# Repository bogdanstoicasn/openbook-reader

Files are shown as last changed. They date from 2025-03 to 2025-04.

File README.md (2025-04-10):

# OpenBook-reader

## Overview

OpenBook is an open-source e-book reader designed to be affordable and customizable. It is built around the ESP32-C6 microcontroller and integrates an E-Ink display, a Li-Po battery, and a microSD slot for extended storage. The device targets a wide range of users, from hobbyists to developers, who want to create their own e-book reader or modify existing designs.

## Table of Contents

1. [Features](#features)

2. [Data](#data)

3. [Block Diagram](#block-diagram)

4. [Hardware Functionality](#hardware-functionality)

5. [Hardware Components & Datasheets](#hardware-components--datasheets)

6. [Implementation](#implementation)

7. [Design Decisions and Trade-offs](#design-decisions-and-trade-offs)

8. [3D Visualizations](#3d-visualizations)
   
9. [Testing and Debugging](#testing-and-debugging)

10. [Suggestions](#suggestions)

## Features

- **Microcontroller**: ESP32-C6 with Wi-Fi and Bluetooth capabilities

- **Display**: 7.5" E-Ink display with a resolution of  800x480 pixels

- **Storage**: MicroSD card slot for additional storage

- **Battery**: Rechargeable Li-Po battery with a capacity of 2500mAh

- **Connectivity**: Wi-Fi 6, Bluetooth 5.0, and USB-C for charging and data transfer

- **Sensors**: Integrated environmental sensor (BME680) for temperature, humidity, pressure, and gas measurements

- **Real-Time Clock**: DS3231 for accurate timekeeping

- **User Interface**: 3 tactile buttons for navigation and control

## Data

Dimension: 175mm x 114mm x 10mm

Weight: 250g
Supported file formats: EPUB, PDF, TXT, FB2.

Operating system: FreeRTOS

Charging: 5V/1A via USB-C

## Block Diagram

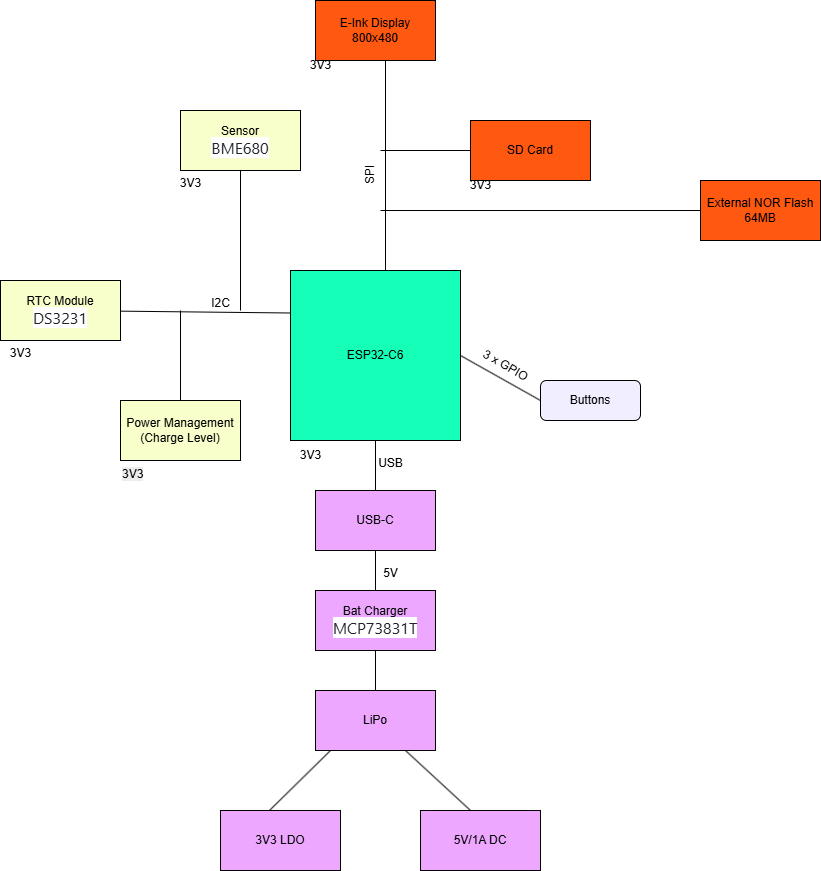
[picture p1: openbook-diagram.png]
Block Diagram


## Hardware Functionality

### Microcontroller:

The ESP32-C6 is the main processing unit, responsible for handling all system operations, including e-paper display updates, wireless communication, and power management. It features:

- RISC-V architecture 32-bit core

- 2.4 GHz Wi-Fi and Bluetooth 5.0 connectivity

-  160 MHz clock speed with 4 stage pipeline

- L1 chache 16KB

- ROM 320KB

- SRAM 512KB(HP) + 16KB (LP)

- 30 GPIO pins

Power consumption: 160uA in deep sleep mode, 10mA in active mode

### Display:

- Type: E-Ink (E-Paper) display

- Size: 7.5 inches

- Resolution:  800x480 pixels

- Communication: SPI interface

- Power consumption: ~1.2mW in active mode, ~0.1mW in standby mode

Connection to the ESP32-C6 and other modules:

> IO7 -> MOSI(14)

> IO6 -> SCK(13)

> IO10 -> EPD_CS(12)

> IO5 -> EPD_DC(11)

> IO23 -> EPD_RST(10)

> IO3 -> EPD_BUSY(9)

Connection to power:

> EPD_3V3 -> 3.3V

### MicroSD Card

- Type: MicroSD card

- Capacity: Up to 32GB (FAT32 format)

- Communication: SPI interface

- Power consumption: ~50mA during read/write operations, ~10uA in standby mode

Connection to the ESP32-C6 and other modules:

> IO7 -> MOSI(CMD)

> IO6 -> SCK(CLK)

> IO4 -> SS_SD(CD/DAT3)

> IO2 -> MISO(DAT0)

### Battery and Power Management

- Type: Li-Po battery

- Capacity: 2500mAh

- Voltage: 3.7V nominal, 4.2V max

- Voltage regulator: MCP73831T for charging and power management

- Charging: 5V/1A via USB-C

- Power consumption: ~10mA during active mode, less than 50uA in deep sleep mode

Connection to the ESP32-C6 and other modules:

> CELL -> BAT

> IO21 -> SDA(SDA)

> IO22 -> SCL(SCL)

### Environmental Sensor

- Type: BME680

- Measurement: Temperature, humidity, pressure, and gas

- Communication: I2C interface

- Power consumption: ~3.6mA during measurement, ~0.1uA in sleep mode

Connection to the ESP32-C6 and other modules:

> IO21 -> SDA(SDI)

> IO22 -> SCL(SCK)

> IO19 -> I2C_PW(VDDIO)

### Real-Time Clock

- Type: DS3231

- Function: Accurate timekeeping

- Communication: I2C interface

- Power consumption: ~1.5uA in battery backup mode, ~0.1uA in sleep mode

Connection to the ESP32-C6 and other modules:

> IO21 -> SDA(15)

> IO22 -> SCL(16)

> IO18 -> RTC_RST(RST)

> IO1 -> 32KHz(32KHz)

> IO0 -> INT_RTC(SQW/INT)

### External Nor Flash

- Type: SPI Flash

- Capacity: 64MB

- Communication: SPI interface

- Power consumption: ~10mA during read/write operations, ~0.1uA in standby mode

Connection to the ESP32-C6 and other modules:

> IO11 -> EPD_CS(CS)

> IO6 -> SCK(CLK)

> IO2 -> MISO(DO/IO1)

> IO7 -> MOSI(DI/IO0)

### USB-C Connector

- Type: USB-C connector

- Function: Charging and data transfer

- Power consumption: ~5V/1A during charging, ~0.1uA in standby mode

- Protection: PFMF varistor for ESD protection

- Diode: Schottky barrier rectifier diode for reverse polarity protection

### Buttons

- Type: Tactile push buttons

- Number: 3

- Function: User input for navigation and control

Connection to the ESP32-C6 and other modules:

> EN -> RESET

> IO9 -> IO/BOOT

> IO15 -> IO/CHANGE

### Calculations

| Component | Current Draw (mA) | Voltage (V) | Power (mW) |
|---|---|---|---|
| ESP32-C6  | 10 | 3.3 | 33 |
| E-Ink Display | 1.2 | 3.3 | 3.96 |
| MicroSD Card | 50 | 3.3 | 165 |
| BME680 | 3.6 | 3.3 | 11.88 |
| DS3231 | 0.015 | 3.3 | 0.0495 |
| MCP73831T | 10 | 3.3 | 33 |
| USB-C Connector | 5 | 5 | 25 |
| External Flash | 10 | 3.3 | 33 |

Total Power Consumption: 304.3 mW
Total Current Draw: 89.8 mA

## Hardware Components & Datasheets

| Name | Description | Num | Datasheet | Price |
|---|---|-----|---|---|
| Micro-SD | Micro-Sd | 1 | https://www.attend.com.tw/data/download/file/112A-TAAR-R03_Spec.pdf | https://www.digikey.com/en/products/detail/attend-technology/112A-TAAR-R03/17633923 |
| Inductor | 68uH | 1 | https://www.we-online.com/components/products/datasheet/784373170680.pdf | https://eu.mouser.com/ProductDetail/Wurth-Elektronik/784373170680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 |
| Led | No description | 1 | https://www.bridgelux.com/sites/default/files/resource_media/DS51_Rev%20F%20Bridgelux%20SMD%203030%20Data%20sheet.pdf | https://www.digikey.com/en/products/detail/bridgelux/BXEM-27E0000-0-000/6618599 |
| Voltage Detector | With Adjustable Delay Time | 1 | https://www.rohm.com/datasheet?p=BD5229G&dist=Digi-key&media=referral&source=digi-key.com&campaign=Digi-key | https://www.digikey.com/en/products/detail/rohm-semiconductor/BD5229G-TR/658502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 |
| Buttons | No description | 3 | https://configured-product-images.s3.amazonaws.com/Datasheets/TL3315.pdf | https://www.digikey.com/en/products/detail/e-switch/TL3315NF250Q/1870396 |
| Super Capacitor | 0.011F 3.3V | 1 | https://mm.digikey.com/Volume0/opasdata/d220001/medias/docus/6537/rev05-CPHCPM.pdf | https://www.digikey.com/en/products/detail/seiko-instruments/cph3225a/8692444 |
| Real Time Clock | Serial 16-Pin SOIC | 1 | https://www.analog.com/media/en/technical-documentation/data-sheets/DS3231.pdf | https://www.digikey.com/en/products/detail/analog-devices-inc-maxim-integrated/DS3231SN/1197576 |
| Capacitor | 8 x 100uF + 6 x 4.7 uF + 1uF x 11 + 1 x 10uF -> Check this capacitor series(look at capacitance code to buy from the specs)| 26 | https://eu.mouser.com/datasheet/2/40/cx5r_KGM-3223198.pdf | https://eu.mouser.com/ProductDetail/KYOCERA-AVX/0402YD104MAT2A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 |
| ESP32-C6-WROOM-1-N8 | Microcontroller of choice | 1 | https://www.espressif.com/sites/default/files/documentation/esp32-c6-wroom-1_wroom-1u_datasheet_en.pdf | https://www.digikey.com/en/products/detail/espressif-systems/ESP32-C6-WROOM-1-N8/17728866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 |
| Varsistor | Used in the USB Connector zone | 1 | https://ro.mouser.com/datasheet/2/358/typ_PFMF-1275918.pdf | https://ro.mouser.com/ProductDetail/Schurter/PFMF.050.2?qs=1auRipcfynCums5v1iucSA%3D%3D |
| Diode | Schottky Barrier Rectifier Diode | 2 | https://datasheets.kyocera-avx.com/schottky.pdf | https://www.digikey.com/en/products/detail/kyocera-avx/sd0805s020s1r0/3749517 |
| Integrated Environmental Unit | Sensor | 1 | https://www.bosch-sensortec.com/media/boschsensortec/downloads/datasheets/bst-bme680-ds001.pdf | https://www.digikey.com/en/products/detail/bosch-sensortec/bme680/7401317 |
| Resistor | Search on DigiKey 0402 smd resistor x (size). The link contains both the site to but from and the datasheet in the order from 'Num' coloumn. |5K1 x 1 + 100K x 1 + 10K x 16 + 0.47 x 1 + 2K x 1 + 200 x 1 + 15 x 1 | [https://www.yageo.com/upload/media/product/products/datasheet/rchip/PYu-RC_Group_51_RoHS_L_12.pdf](https://www.digikey.com/en/products/detail/yageo/RC0402FR-075K1L/726624) - https://www.digikey.com/en/products/detail/yageo/RC0402JR-07100KL/726416 - https://www.digikey.com/en/products/detail/yageo/RC0402JR-0710KL/726418 - https://www.digikey.com/en/products/detail/cts-resistor-products/73L1R47J/1543472 - https://www.digikey.com/en/products/detail/panasonic-electronic-components/ERJ-2RKF2001X/192194 - https://www.digikey.com/en/products/detail/panasonic-electronic-components/ERJ-2RKF2000X/192215 - https://www.digikey.com/en/products/detail/panasonic-electronic-components/ERJ-2RKF15R0X/192142 | Check the 'Datasheet' section |
| P-channel MOSFETs | DMG2305UX-7 | 2 | https://www.diodes.com/assets/Datasheets/DMG2305UX.pdf | https://www.digikey.com/en/products/detail/diodes-incorporated/DMG2305UX-7/4340667 | 
| Li-Ion, Li-Pol Controller | MCP73831T | 1 | https://ww1.microchip.com/downloads/en/DeviceDoc/MCP73831-Family-Data-Sheet-DS20001984H.pdf | https://www.digikey.com/en/products/detail/microchip-technology/MCP73831T-2ACI-OT/964301 |
| Hirose Connector | 24 Position FFC, FPC Connector Contacts, Top and Bottom 0.020" (0.50mm) Surface Mount, Right Angle | 1 | https://ro.mouser.com/datasheet/2/185/FH34SRJ_24S_0_5SH_99__CL0580_1255_6_99_2DDrawing_0-1615044.pdf | https://ro.mouser.com/ProductDetail/Hirose-Connector/FH34SRJ-24S-0.5SH99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 |
| Battery Monitor IC | 3µA 1-Cell/2-Cell Fuel Gauge with ModelGauge | 1 | https://datasheets.maximintegrated.com/en/ds/MAX17048-MAX17049.pdf | https://www.digikey.com/en/products/detail/analog-devices-inc-maxim-integrated/MAX17048G-T10/3758921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 |
| Diode | DIODE, SCHOTTKY, 0.5A, 30V, SOD-123 | 3 | https://ro.mouser.com/datasheet/2/258/MBR0520_MBR0580_SOD123_-2492194.pdf | https://ro.mouser.com/ProductDetail/Micro-Commercial-Components-MCC/MBR0530-TP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. |
| Diode | ESD Suppressor Diode Polymer Bi-Dir 24V 150Vc 2-Pin Case 0603(1608Metric) T/R | 6 | https://www.littelfuse.com/assetdocs/pulseguard-esd-suppressors-pgb1-datasheet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 | https://www.digikey.com/en/products/detail/littelfuse-inc/PGB1010603MR/715755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 |
| Qwiic Connector | SparkFun I2C Standard Qwiic Connector | 1 | Check https://www.sparkfun.com/qwiic | https://www.digikey.com/en/products/detail/onion-corporation/om-e-qwiic/9922970 |
| Capacitor | Polarized, 0.5pF ~ 100uF | 1 | https://ro.mouser.com/datasheet/2/281/1/GCQ1555C1HR50WB01_01A-3146956.pdf | https://ro.mouser.com/ProductDetail/Murata-Electronics/GCQ1555C1HR50WB01D?qs=0lQeLiL1qybSG%2FOlONlvIA%3D%3D |
| Connector USB | CONN USB 2.0 TYPE-C R/A SMT | 1 | https://gct.co/files/drawings/usb4110.pdf | https://eu.mouser.com/ProductDetail/GCT/USB4110-GF-A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 |
| N-channel MOSFETs | Mosfet N-Channel 30 V 1.4A (Tc) 400mW (Ta), 500mW (Tc) Surface Mount SC-70-3 (SI1308EDL-T1-GE3)| 1 | https://www.vishay.com/docs/63399/si1308edl.pdf | https://www.digikey.com/en/products/detail/vishay-siliconix/si1308edl-t1-ge3/4876435 |
| Solder Jumper | We can use 0 ohms resistor | 1 | https://industrial.panasonic.com/ww/products/pt/general-purpose-chip-resistors/models/ERJ2GE0R00X | https://www.digikey.com/en/products/detail/panasonic-electronic-components/ERJ-2GE0R00X/146727 |
| Test Pad | Testing points for the PCB (Adafruit). | 17 | https://analytics.supplyframe.com/trackingservlet/track/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 | https://componentsearchengine.com/prices/3825?manufacturer=Adafruit |

## Implementation

### Initial Setup and Tool Selection

- Choose your PCB design software(Fusion360)

- Prepare the mechanical dimensions and casing files provided

### Create the Schematic

- Add the ESP32-C6 microcontroller, power components, display interfaces, buttons, and other required components

- Ensure the pin configuration for the ESP32-C6 matches the required hardware interfaces (e.g., SPI for the display, I2C for sensors).

- Implement decoupling capacitors near the power pins

- Electrical Design Validation (EVT)

### PCB Layout Design

- Place major components like the ESP32, display, and battery connectors according to the provided layout recommendations

- Route the traces carefully, avoiding sharp angles and placing vias in non-critical signal paths

- Design Rule Check(DRC)

### Mechanical Design Integration

- Create 3D models for case, battery and display for integration

- Verify that all components fit within the casing and that connectors like USB and SD card slots align with physical cutouts

## Design Decisions and Trade-offs

- Decoupling capacitors(100nF) should be placed close to the power pins of major components.

- Power traces width: 0.3mm

- Power traces were routed without vias to ensure low impedance and reliable power delivery.

- Signal traces width: 0.15mm

- No routing under ESP antenna.

- 2 layers PCB with 2 ground planes.

- All components on TOP Layer.

- Test pads were placed close to the relevant signals to facilitate easier probing and debugging.

- PCB cut near ESP32-C6 antenna for better signal, with a keep-out zone to reduce interference.

- The ESP32-C6 features multiple low-power modes (including deep sleep and light sleep) and efficient power domain management.

- Via stitching under the ESP32-C6 is beneficial for improving thermal dissipation and electromagnetic interference (EMI) performance.

- The PCB layout follows the reference design shown in Images/layout_reference.pdf.

- All PCB traces are routed to avoid 90-degree angles to ensure signal integrity and reduce the risk of electromagnetic interference (EMI).

- The 3D connection model for the display has been designed to provide a realistic representation of the **Display**; however, the connection model it's not flexible(used just for accurate display representation).

- The models for the battery and display are included to mimic their real-world sizes for visualization purposes. They do not reflect the actual hardware functionality or internal components.

- Integrating ESD protection helps safeguard sensitive components—like the ESP32-C6 and display driver—from electrostatic discharge events

## 3D Visualizations

### PCB

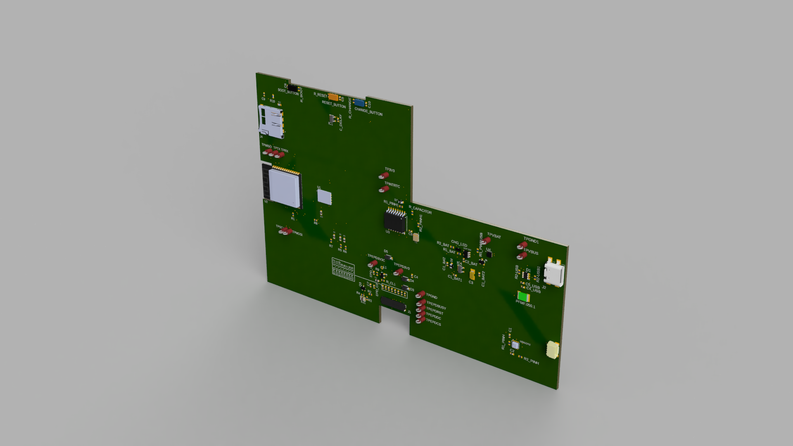
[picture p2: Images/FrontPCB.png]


### Battery

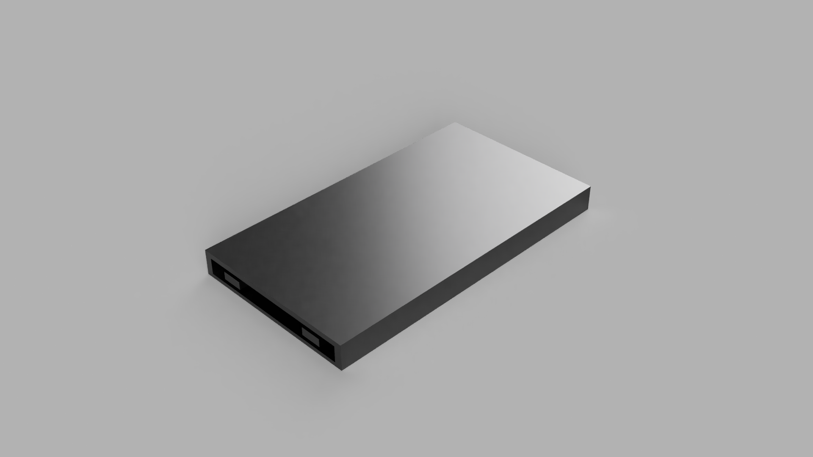
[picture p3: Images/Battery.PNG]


### Display

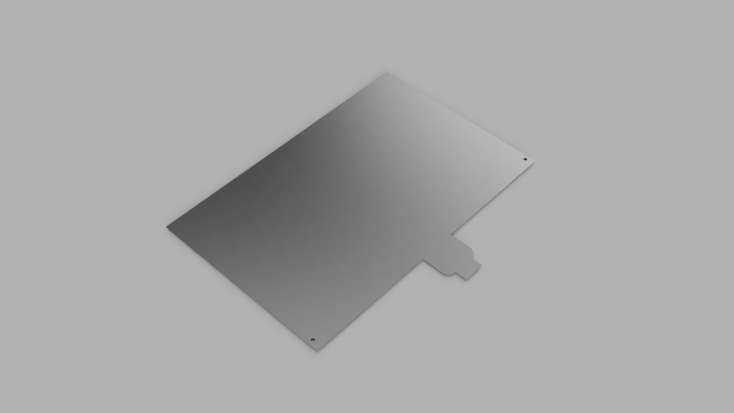
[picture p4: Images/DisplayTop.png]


### Full Product

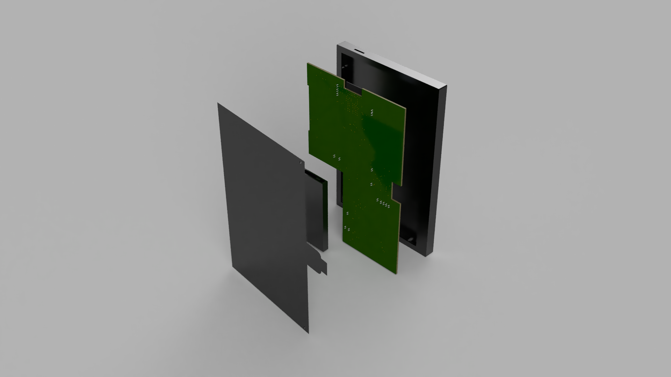
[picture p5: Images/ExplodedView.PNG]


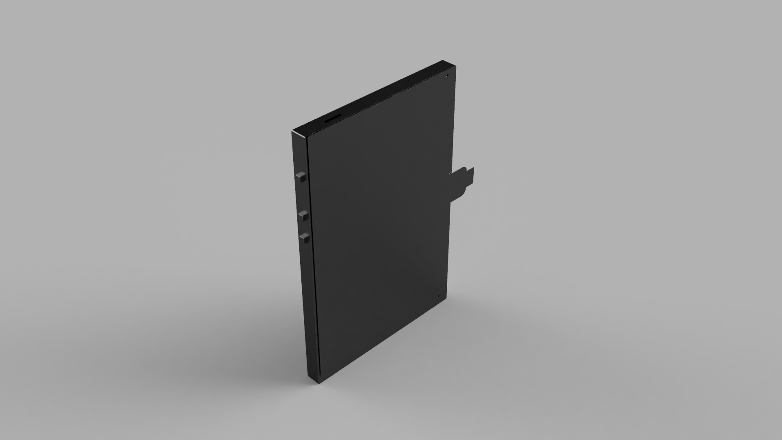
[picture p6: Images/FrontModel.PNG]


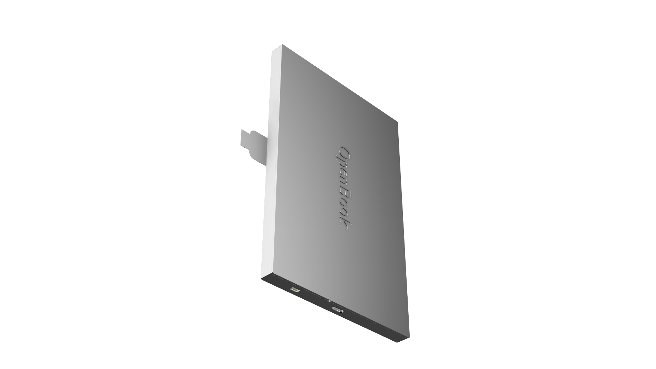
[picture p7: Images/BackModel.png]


## Testing and Debugging

The OpenBook PCB has test pads for each major communication and power line.

1. TPRX - RX signal
2. TPTX - TX signal
3. TPVBAT - Battery voltage
4. 2 x TPGND - Ground
5. TP3V3 - 3.3V power
6. TPEPD_3V3 - EPD 3.3V power
7. TPMISO - MISO signal
8. TPMOSI - MOSI signal
9. TPSCK - SCK signal
10. TPEPDBUSY - EPD BUSY signal
11. TPEPDCS - EPD CS signal
12. TPEPDDC - EPD DC signal
13. TPEPDRST - EPD RST signal
14. TPEPD3V3C - EPD 3.3V power
15. TPVBUS - VBUS voltage
16. TPINTRTC - RTC interrupt signal

## Suggestions

- Operating system: FreeRTOS

- Programming language: C/C++

- IDE: PlatformIO or Arduino IDE

- Libraries: ESP-IDF, EPD library, SD card library, BME680 library, DS3231 library

- Communication protocols: SPI, I2C, UART

- Power management: Use deep sleep mode to save power when not in use

- User interface: Use a simple menu system for navigation and control

- File management: Implement a file system for easy access to e-books on the microSD card

- E-book reader software: Use an existing open-source e-book reader software or develop a custom solution

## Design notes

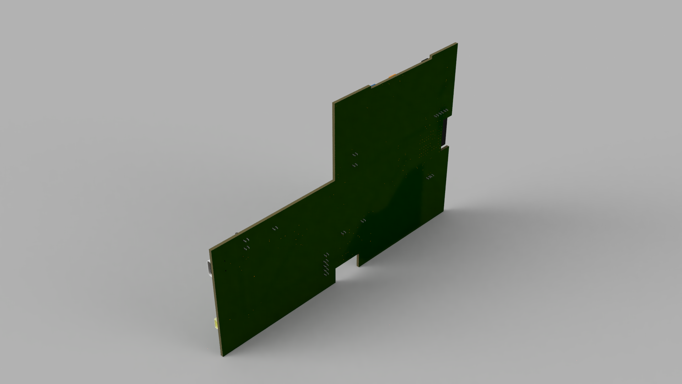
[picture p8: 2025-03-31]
Images/BackPCB.PNG

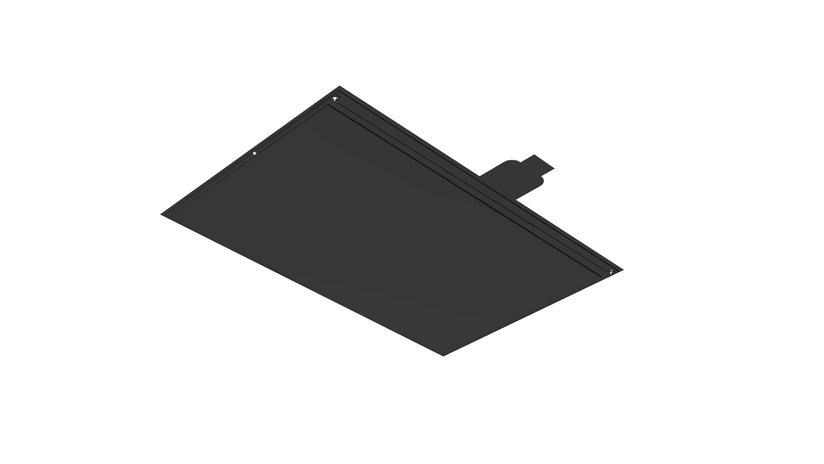
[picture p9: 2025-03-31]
Images/DisplayBottom.png

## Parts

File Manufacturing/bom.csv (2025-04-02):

Qty | Value | Device | Package | Parts | Description | ARROW_PART_NUMBER | ARROW_PRICE-STOCK | AVAILABILITY | CATEGORY | CENTROID_NOT_SPECIFIED | CHECK_PRICES | CURRENT_RATING | DATASHEET | DESCRIPTION | DIGIKEY_DESCRIPTION | DIGIKEY_PART_NUMBER | HEIGHT | LEAD_FREE | MANUFACTURER | MANUFACTURER_NAME | MANUFACTURER_PART_NUMBER | MF | MOUSER_PART_NUMBER | MOUSER_PRICE-STOCK | MOUSER_TESTING_PART_NUMBER | MOUSER_TESTING_PRICE-STOCK | MP | MPN | OPERATING_TEMP | PACKAGE | PART_STATUS | POPULARITY | PREFIX | PRICE | PROD_ID | PURCHASE-URL | ROHS | ROHS_COMPLIANT | SERIES | SNAPEDA_LINK | SPICEMODEL | SPICEPREFIX | SUB-CATEGORY | TEMPERATURE_RANGE_HIGH | TEMPERATURE_RANGE_LOW | THERMALLOSS | TP_SIGNAL_NAME | TYPE | VALUE
1 |  | ADAFRUIT_LEDCHIP-LED0603 | ADAFRUIT_CHIP-LED0603 | CHG_LED | LED
1 |  | SJ | SJ | SJ1 | SMD solder JUMPER |  |  |  |  |  |  |  |  |  |  |  |  |  |  |  |  |  |  |  |  |  |  |  |  |  |  | 3
1 | 0.1uF/50V | EAGLE-LTSPICE_CC0402 | EAGLE-LTSPICE_C0402 | EPD_C5 | CAPACITOR, European symbol |  |  |  |  |  |  |  |  |  |  |  |  |  |  |  |  |  |  |  |  |  |  |  |  |  |  |  |  |  |  |  |  |  |  |  | NONE | C
1 | 0.47 | ESP32_WROVER_EAGLE-LTSPICE_RR0402 | ESP32_WROVER_EAGLE-LTSPICE_R0402 | R3 | RESISTOR, European symbol |  |  |  |  |  |  |  |  |  |  |  |  |  |  |  |  |  |  |  |  |  |  |  |  |  |  |  |  |  |  |  |  |  |  |  | NONE | R
1 | 100K | ESP32_WROVER_EAGLE-LTSPICE_RR0402 | ESP32_WROVER_EAGLE-LTSPICE_R0402 | R1_PWRUSB | RESISTOR, European symbol |  |  |  |  |  |  |  |  |  |  |  |  |  |  |  |  |  |  |  |  |  |  |  |  |  |  |  |  |  |  |  |  |  |  |  | NONE | R
8 | 100nF | EAGLE-LTSPICE_CC0402 | EAGLE-LTSPICE_C0402 | C1, C2, C4_USB, C6, C8, C9, C10, C_DELAY | CAPACITOR, European symbol |  |  |  |  |  |  |  |  |  |  |  |  |  |  |  |  |  |  |  |  |  |  |  |  |  |  |  |  |  |  |  |  |  |  |  | NONE | C
1 | 100uF TANT | RCL_CPOL-EUCT3528 | RCL_CT3528 | C3 | POLARIZED CAPACITOR, European symbol |  |  |  |  |  |  |  |  |  |  |  |  |  |  |  |  |  |  |  |  |  |  |  |  |  |  | 0 |  |  |  |  |  |  |  |  |  | C
16 | 10K | ESP32_WROVER_EAGLE-LTSPICE_RR0402 | ESP32_WROVER_EAGLE-LTSPICE_R0402 | R1, R1_PINH, R1_PINH1, R2_PINH, R2_PINH1, R4, R5, R6, R7, R8, R9, R10, R_BOOT, R_CHANGE, R_CL1, R_RESET | RESISTOR, European symbol |  |  |  |  |  |  |  |  |  |  |  |  |  |  |  |  |  |  |  |  |  |  |  |  |  |  |  |  |  |  |  |  |  |  |  | NONE | R
1 | 10uF | EAGLE-LTSPICE_CC0402 | EAGLE-LTSPICE_C0402 | C7 | CAPACITOR, European symbol |  |  |  |  |  |  |  |  |  |  |  |  |  |  |  |  |  |  |  |  |  |  |  |  |  |  |  |  |  |  |  |  |  |  |  | NONE | C
1 | 112A-TAAR-R03_ATTEND | 112A-TAAR-R03_ATTEND | 112ATAARR03ATTEND | J4 | Micro SD Card Socket, Push-Push Type, Top Mount, SMT, H=1.83mm, 10u |  |  |  |  |  |  |  |  | Micro SD Card Socket | Push-Push Type | Top Mount | SMT | H=1.83mm | 10u |  |  | 1.9mm |  |  | ATTEND | 112A-TAAR-R03 ATTEND
1 | 15 | ESP32_WROVER_EAGLE-LTSPICE_RR0402 | ESP32_WROVER_EAGLE-LTSPICE_R0402 | R_CAPACITOR | RESISTOR, European symbol |  |  |  |  |  |  |  |  |  |  |  |  |  |  |  |  |  |  |  |  |  |  |  |  |  |  |  |  |  |  |  |  |  |  |  | NONE | R
1 | 1uF | EAGLE-LTSPICE_CC0402 | EAGLE-LTSPICE_C0402 | C5 | CAPACITOR, European symbol |  |  |  |  |  |  |  |  |  |  |  |  |  |  |  |  |  |  |  |  |  |  |  |  |  |  |  |  |  |  |  |  |  |  |  | NONE | C
9 | 1uF/50V | EAGLE-LTSPICE_CC0402 | EAGLE-LTSPICE_C0402 | EPD_C1, EPD_C2, EPD_C6, EPD_C7, EPD_C8, EPD_C9, EPD_C10, EPD_C11, EPD_C12 | CAPACITOR, European symbol |  |  |  |  |  |  |  |  |  |  |  |  |  |  |  |  |  |  |  |  |  |  |  |  |  |  |  |  |  |  |  |  |  |  |  | NONE | C
1 | 2.2 | ESP32_WROVER_EAGLE-LTSPICE_RR0402 | ESP32_WROVER_EAGLE-LTSPICE_R0402 | R2 | RESISTOR, European symbol |  |  |  |  |  |  |  |  |  |  |  |  |  |  |  |  |  |  |  |  |  |  |  |  |  |  |  |  |  |  |  |  |  |  |  | NONE | R
1 | 200 | ESP32_WROVER_EAGLE-LTSPICE_RR0402 | ESP32_WROVER_EAGLE-LTSPICE_R0402 | R1_BAT | RESISTOR, European symbol |  |  |  |  |  |  |  |  |  |  |  |  |  |  |  |  |  |  |  |  |  |  |  |  |  |  |  |  |  |  |  |  |  |  |  | NONE | R
2 | 20V/4.2A/52mO/1.4W | ESP32_WROVER_SPARKFUN-DISCRETESEMI_MOSFET_PCH-DMG2305UX-7 | ESP32_WROVER_SPARKFUN-DISCRETESEMI_SOT23-3 | Q1, Q2 | P-channel MOSFETs |  |  |  |  |  |  |  |  |  |  |  |  |  |  |  |  |  |  |  |  |  |  |  |  |  |  |  |  |  | TRAN-14388 |  |  |  |  |  |  |  |  |  |  |  |  |  | 20V/4.2A/52mO/1.4W
1 | 2K | ESP32_WROVER_EAGLE-LTSPICE_RR0402 | ESP32_WROVER_EAGLE-LTSPICE_R0402 | R2_BAT | RESISTOR, European symbol |  |  |  |  |  |  |  |  |  |  |  |  |  |  |  |  |  |  |  |  |  |  |  |  |  |  |  |  |  |  |  |  |  |  |  | NONE | R
5 | 4.7uF | EAGLE-LTSPICE_CC0402 | EAGLE-LTSPICE_C0402 | C1_BAT, C1_BAT1, C1_BAT2, C2_BAT, C5_USB | CAPACITOR, European symbol |  |  |  |  |  |  |  |  |  |  |  |  |  |  |  |  |  |  |  |  |  |  |  |  |  |  |  |  |  |  |  |  |  |  |  | NONE | C
1 | 4.7uF/25V | EAGLE-LTSPICE_CC0402 | EAGLE-LTSPICE_C0402 | C4 | CAPACITOR, European symbol |  |  |  |  |  |  |  |  |  |  |  |  |  |  |  |  |  |  |  |  |  |  |  |  |  |  |  |  |  |  |  |  |  |  |  | NONE | C
2 | 5k1 | ESP32_WROVER_EAGLE-LTSPICE_RR0402 | ESP32_WROVER_EAGLE-LTSPICE_R0402 | R2-USB, R2-USB1 | RESISTOR, European symbol |  |  |  |  |  |  |  |  |  |  |  |  |  |  |  |  |  |  |  |  |  |  |  |  |  |  |  |  |  |  |  |  |  |  |  | NONE | R
1 | 68uH | INDUCTOR_CHIP-0402(1006-METRIC) | INDC1006X60N | L1 | Inductor Fixed - Generic |  |  |  | Inductor |  |  |  |  |  |  |  |  |  |  |  |  |  |  |  |  |  |  |  |  |  |  |  |  |  |  |  |  |  |  |  |  |  | Fixed
1 | BD5229G-TR | BD5229G-TR | SOT95P280X125-5N | IC1 | Voltage Detector with Adjustable Delay Time: CMOS processes are utilized to develop high precision, low current consumption CMOS reset ICs that allow arbitrary setting of the delay time. The extensive lineup includes both Nch Open Drain and CMOS output types in a wide range of detection voltages (from 2.3V to 6.0V, in 0.1V steps), enabling selection of the ideal solution based on customer requirements. In addition, the entire series is of course both lead-free and RoHS-compliant. |  |  |  |  |  |  |  |  | Voltage Detector with Adjustable Delay Time: CMOS processes are utilized to develop high precision | low current consumption CMOS reset ICs that allow arbitrary setting of the delay time. The extensive lineup includes both Nch Open Drain and CMOS output types in a wide range of detection voltages (from 2.3V to 6.0V | in 0.1V steps) | enabling selection of the ideal solution based on customer requirements. In addition | the entire series is of course both lead-free and RoHS-compliant. |  |  | 1.25mm |  |  | ROHM Semiconductor | BD5229G-TR |  | 755-BD5229G-TR | https://www.mouser.co.uk/ProductDetail/ROHM-Semiconductor/BD5229G-TR?qs=4kLU8WoGk0vvnhrrYwdszw%3D%3D
1 | BME688 | ESP32_WROVER_BME680_BME680 | ESP32_WROVER_BME680_PSON80P300X300X100-8N | SENSOR2 | Integrated Environmental Unit |  |  | Unavailable |  |  |  |  |  | Integrated Environmental Unit |  |  |  |  |  |  |  | Bosch Sensortec |  |  |  |  | BME680 |  |  | LGA-8 Bosch Tools |  |  |  | None
3 | BUTTON_CUSYOMV1 | BUTTON_CUSYOMV1 | MYBUTTON | BOOT_BUTTON, CHANGE_BUTTON, RESET_BUTTON
1 | CPH3225A | CPH3225A | CAPCP3225X100N | C11 | Cap 0.011F 3.3V 1210 Flat Check availability |  |  | Not in stock |  |  | https://www.snapeda.com/parts/CPH3225A/Seiko+Instruments/view-part/?ref=eda |  |  | 11 mF (EDLC) Supercapacitor 3.3 V 1210 (3225 Metric) - - |  |  |  |  |  |  |  | Seiko Instruments |  |  |  |  | CPH3225A |  |  | 1210 Seiko |  |  |  | None |  | https://www.snapeda.com/api/url_track_click_mouser/?unipart_id=562593&manufacturer=Seiko Instruments&part_name=CPH3225A&search_term=None |  |  |  | https://www.snapeda.com/parts/CPH3225A/Seiko+Instruments/view-part/?ref=snap
1 | DS3231SN# | DS3231SN# | SOIC127P1032X265-16N | U3 | Real Time Clock Serial 16-Pin SOIC W T/R Check availability |  |  | In Stock |  |  | https://www.snapeda.com/parts/DS3231SN%23/Analog+Devices/view-part/?ref=eda |  |  | Extremely Accurate I²C-Integrated RTC/TCXO/Crystal |  |  |  |  |  |  |  | Analog Devices |  |  |  |  | DS3231SN# |  |  | SOIC-16 Maxim |  |  |  | None |  | https://www.snapeda.com/api/url_track_click_mouser/?unipart_id=99048&manufacturer=Analog Devices&part_name=DS3231SN#&search_term=None |  |  |  | https://www.snapeda.com/parts/DS3231SN%23/Analog+Devices/view-part/?ref=snap
1 | ESP32-C6-WROOM-1-N8 | ESP32-C6-WROOM-1-N8 | XCVR_ESP32-C6-WROOM-1-N8 | U2 | Check availability |  |  | In Stock |  |  | https://www.snapeda.com/parts/ESP32-C6-WROOM-1-N8/Espressif+Systems/view-part/?ref=eda |  |  | Multiprotocol Modules ESP32-C6 module | Wi-Fi 6 in 2.4 GHz band | Bluetooth 5 | Zigbee 3.0 and Thread. ESP34-WROOM Compatible - ENGINEERING SAMPLE |  |  |  |  |  |  |  | Espressif Systems |  |  |  |  | ESP32-C6-WROOM-1-N8 |  |  | None |  |  |  | None |  |  |  |  |  | https://www.snapeda.com/parts/ESP32-C6-WROOM-1-N8/Espressif+Systems/view-part/?ref=snap
1 | ESP32C6_VARISTORCN1812 | ESP32C6_VARISTORCN1812 | ESP32C6_VARISTOR_CT/CN1812 | PFMF.050.1 | VARISTOR |  |  |  |  |  |  |  |  |  |  |  |  |  |  |  |  |  |  |  |  |  |  |  |  |  |  | 0
2 | ESP32_WROVER_AVX---SD0805S020S1R0_AVX_SD0805S020S1R0_0_0AVX_SD0805S020S1R0_0_0 | ESP32_WROVER_AVX---SD0805S020S1R0_AVX_SD0805S020S1R0_0_0AVX_SD0805S020S1R0_0_0 | ESP32_WROVER_AVX---SD0805S020S1R0_AVX_SD0805S020S1R0_0 | D2, D7 | Schottky Barrier Rectifier Diode |  |  |  |  | No |  |  | http://datasheets.avx.com/schottky.pdf |  | DIODE SCHOTTKY 20V 1A 0805 | 478-7800-1-ND |  | yes |  |  |  | AVX | 581-SD0805S020S1R0 |  |  |  |  |  |  | 0805 (2012 metric) |  |  | D |  |  |  | yes |  |  |  |  |  |  | +125°C | -55°C
1 | ESP32_WROVER_SPARKFUN-IC-POWER_MCP73831 | ESP32_WROVER_SPARKFUN-IC-POWER_MCP73831 | ESP32_WROVER_SPARKFUN-IC-POWER_SOT23-5 | MCP73831 | MCP73831T Li-Ion, Li-Pol Controller |  |  |  |  |  |  |  |  |  |  |  |  |  |  |  |  |  |  |  |  |  |  |  |  |  |  |  |  |  | IC-09995
1 | FH34SRJ-24S-0.5SH_99_ | FH34SRJ-24S-0.5SH_99_ | FH34SRJ24S05SH99 | J1 | (0.50mm) Surface Mount, Right Angle |  |  |  |  |  |  |  |  | 24 Position FFC | FPC Connector Contacts | (0.50mm) Surface Mount | Right Angle |  |  | 1.1mm |  |  | Hirose | FH34SRJ-24S-0.5SH(99) |  | 798-FH34SRJ24S05SH99 | https://www.mouser.co.uk/ProductDetail/Hirose-Connector/FH34SRJ-24S-0.5SH99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
1 | MAX17048G+T10 | MAX17048G+T10 | SON50P200X200X80-9N | U4 | Check availability |  |  | In Stock |  |  | https://www.snapeda.com/parts/MAX17048G+T10/Analog+Devices/view-part/?ref=eda |  |  | 3µA 1-Cell/2-Cell Fuel Gauge with ModelGauge |  |  |  |  |  |  |  | Analog Devices |  |  |  |  | MAX17048G+T10 |  |  | TDFN-8 Maxim |  |  |  | None |  | https://www.snapeda.com/api/url_track_click_mouser/?unipart_id=329239&manufacturer=Analog Devices&part_name=MAX17048G+T10&search_term=None |  |  |  | https://www.snapeda.com/parts/MAX17048G+T10/Analog+Devices/view-part/?ref=snap
3 | MBR0530 | MBR0530 | SOD3716X135N | D3, D4, D5 | ON SEMICONDUCTOR - MBR0530 - DIODE, SCHOTTKY, 0.5A, 30V, SOD-123 |  |  | In Stock |  |  | https://www.snapeda.com/parts/MBR0530/Onsemi/view-part/?ref=eda |  |  | Diode Schottky 30 V 500mA Surface Mount SOD-123 |  |  |  |  |  |  |  | ON Semiconductor |  |  |  |  | MBR0530 |  |  | SOD-123-2 ON Semiconductor |  |  |  | None |  | https://www.snapeda.com/api/url_track_click_mouser/?unipart_id=179458&manufacturer=ON Semiconductor&part_name=MBR0530&search_term=None |  |  |  | https://www.snapeda.com/parts/MBR0530/Onsemi/view-part/?ref=snap
6 | PGB1010603MR | PGB1010603MR | DIOC1608X36N | D6, D8, D9, D10, D11, D12 | Check availability |  |  | In Stock |  |  | https://www.snapeda.com/parts/PGB1010603MR/Littelfuse/view-part/?ref=eda |  |  | 150V (Typ) Clamp - Ipp Tvs Diode Surface Mount 0603 (1608 Metric) |  |  |  |  |  |  |  | Littelfuse Inc. |  |  |  |  | PGB1010603MR |  |  | 0603 Littelfuse Inc. |  |  |  | None |  | https://www.snapeda.com/api/url_track_click_mouser/?unipart_id=5659453&manufacturer=Littelfuse Inc.&part_name=PGB1010603MR&search_term=None |  |  |  | https://www.snapeda.com/parts/PGB1010603MR/Littelfuse/view-part/?ref=snap
1 | QWIIC_RIGHT_ANGLE | QWIIC_CONNECTORJS-1MM | JST04_1MM_RA | J3 | SparkFun I2C Standard Qwiic Connector |  |  |  |  |  |  |  |  |  |  |  |  |  |  |  |  |  |  |  |  |  |  |  |  |  |  |  |  |  | CONN-13694 |  |  |  |  |  |  |  |  |  |  |  |  |  | QWIIC_RIGHT_ANGLE
1 | SAMACSYS_PARTS_USB4110-GF-A | SAMACSYS_PARTS_USB4110-GF-A | SAMACSYS_PARTS_USB4110GFA | J2 | CONN USB 2.0 TYPE-C R/A SMT |  |  |  |  |  |  |  |  | CONN USB 2.0 TYPE-C R/A SMT |  |  | 3.26mm |  |  | GCT (GLOBAL CONNECTOR TECHNOLOGY) | USB4110-GF-A |  | 640-USB4110-GF-A | https://www.mouser.co.uk/ProductDetail/GCT/USB4110-GF-A?qs=KUoIvG%2F9IlYiZvIXQjyJeA%3D%3D
1 | SI1308EDL-T1-GE3 | SI1308EDL-T1-GE3 | SOT65P210X110-3N | Q3 | MOSFET N-Ch 30V 1.5A TrenchFET SC70 Vishay Si1308EDL-T1-GE3 N-channel MOSFET Transistor, 1.5 A, 30 V, 3-Pin SC-70 |  |  | In Stock |  |  | https://www.snapeda.com/parts/SI1308EDL-T1-GE3/Vishay+Siliconix/view-part/?ref=eda |  |  | Si1308EDL-T1-GE3 N-channel MOSFET Transistor | 1.5 A | 30 V | 3-Pin SC-70 | Siliconix / Vishay SI1308EDL-T1-GE3 |  |  |  |  |  |  |  | Vishay Siliconix |  |  |  |  | SI1308EDL-T1-GE3 |  |  | SOT-323 Vishay Semiconductor |  |  |  | None |  | https://www.snapeda.com/api/url_track_click_mouser/?unipart_id=274603&manufacturer=Vishay Siliconix&part_name=SI1308EDL-T1-GE3&search_term=None |  |  |  | https://www.snapeda.com/parts/SI1308EDL-T1-GE3/Vishay+Siliconix/view-part/?ref=snap
17 | TPTP20R | TPTP20R | TP20R | TP3V3, TPEPD3V3, TPEPD3V3C, TPEPDBUSY, TPEPDCS, TPEPDDC, TPEPDRST, TPGND, TPGND1, TPINTRTC, TPMISO, TPMOSI, TPRX, TPSCK, TPTX, TPVBAT, TPVBUS | Test pad |  |  |  |  |  |  |  |  |  |  |  |  |  |  |  |  |  |  |  |  |  |  |  |  |  |  | 2
1 | USBLC6-2SC6Y | USBLC6-2SC6Y | SOT95P280X145-6N | D1 | Low Cap. ESD Protection Auto SOT-23-6 STMicroelectronics USBLC6-2SC6Y, Dual Uni-Directional TVS Diode Array, 6-Pin SOT-23 |  |  | In Stock |  |  | https://www.snapeda.com/parts/USBLC6-2SC6Y/STMicroelectronics/view-part/?ref=eda |  |  | 17V Clamp 5A (8/20µs) Ipp Tvs Diode Surface Mount SOT-23-6 |  |  |  |  |  |  |  | STMicroelectronics |  |  |  |  | USBLC6-2SC6Y |  |  | SOT-23-6 STMicroelectronics |  |  |  | None |  |  |  |  |  | https://www.snapeda.com/parts/USBLC6-2SC6Y/STMicroelectronics/view-part/?ref=snap
1 | W25Q512JVEIQ | W25Q512JVEIQ | SON127P600X800X80-9N | U1 | Check availability |  |  | In Stock |  |  | https://www.snapeda.com/parts/W25Q512JVEIQ/Winbond+Electronics/view-part/?ref=eda |  |  | FLASH - NOR Memory IC 512Mb (64M x 8) SPI - Quad I/O 133 MHz 8-WSON (8x6) |  |  |  |  |  |  |  | Winbond Electronics |  |  |  |  | W25Q512JVEIQ |  |  | Package |  |  |  | None |  |  |  |  |  | https://www.snapeda.com/parts/W25Q512JVEIQ/Winbond+Electronics/view-part/?ref=snap
1 | XC6220A331MR-G | XC6220A331MR-G | SOT95P280X120-5N | IC4 | LDO Voltage Regulators |  |  |  |  |  |  |  |  | LDO Voltage Regulators |  |  | 1.2mm |  |  | Torex | XC6220A331MR-G |  | 865-XC6220A331MR-G | https://www.mouser.co.uk/ProductDetail/Torex-Semiconductor/XC6220A331MR-G?qs=AsjdqWjXhJ8ZSWznL1J0gg%3D%3D

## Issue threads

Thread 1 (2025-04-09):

[DOC] Add "Implementation steps" section

mariaenescu, 2025-04-09:
The current `README.md` lacks a clear description of the implementation process. Consider adding a short section outlining the _key steps_ taken during project development.

**Acceptance criteria**:
- Include a clear list of **implementation steps**.
- Use a logical or **chronological structure**.

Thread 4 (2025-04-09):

[DOC] Add photo showing PCB components and battery placement in the case

mariaenescu, 2025-04-09:
It would be useful to include an additional image in the `README.md`, clearly showing the PCB components and the battery placed inside the casing.

This helps demonstrate that all components fit properly and are uniformly arranged.

Closed 2025-04-10.

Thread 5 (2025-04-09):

[PCB] Missing via stitching around ESP32 on PCB

mariaenescu, 2025-04-09:
When inspecting the `OpenBookReaderv113.brd` file, there appears to be no **via stitching** present around the ESP32 module — neither in the 2D PCB layout nor in the 3D model.

**Add via stitching** around the ESP32.

Update `.brd` file and 3D view to reflect the change.

Closed 2025-04-14.

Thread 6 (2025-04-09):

[PCB] Component layout does not fully match reference PCB pdf

mariaenescu, 2025-04-09:
While most large components appear to be placed in approximately correct areas, the layout of components on the PCB does not fully match the reference layout from the provided PDF.

**Notably:**
- Several components are not rotated or aligned exactly as in the reference(e.g. R1_PINH1, D3, R8 etc.).
- Component spacing and positioning differ from the expected pattern.

Closed 2025-04-09.

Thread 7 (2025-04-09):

[PCB] Unused board outline remains in antenna cutout area

mariaenescu, 2025-04-09:
Although a cutout has been made for the antenna (as required), the original board outline line was not removed and is still visible overlapping the cutout in the PCB design.

Remove the leftover outline segment inside the antenna cutout area.

Ensure the PCB contour is clean, with a single continuous outline.

Closed 2025-04-14.

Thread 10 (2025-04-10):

[PCB] Avoid 90-degree trace angles

mariaenescu, 2025-04-10:
The `PCB` layout currently includes 90-degree angles on the _MOSI_ and _SDA_ signal traces. While _GND_ trace angles may remain as-is due to their low-frequency nature, signal lines like **MOSI and SDA should be re-routed**.

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

Closed 2025-04-14.

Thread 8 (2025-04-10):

[Pnp.csv] Missing column headers in exported pick-and-place file

mariaenescu, 2025-04-10:
The exported `PnP.csv` file is **missing the column headers**. It starts directly with the first data row, which may cause confusion when importing into assembly tools or when manually reading the file.

Ensure the file includes a header row with the appropriate column names(e.g. _Ref Des_, _Mid X_, _Mid Y_, _Rotation_, _Comment_, _Package_)

Closed 2025-04-10.

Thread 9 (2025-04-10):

[Schematic] Fix overlapping net labels

mariaenescu, 2025-04-10:
The net labels are currently **overlapping in the schematic**, which reduces readability.

**Resize** the labels to fit the available space, or move them slightly apart to avoid visual overlap.

Closed 2025-04-14.

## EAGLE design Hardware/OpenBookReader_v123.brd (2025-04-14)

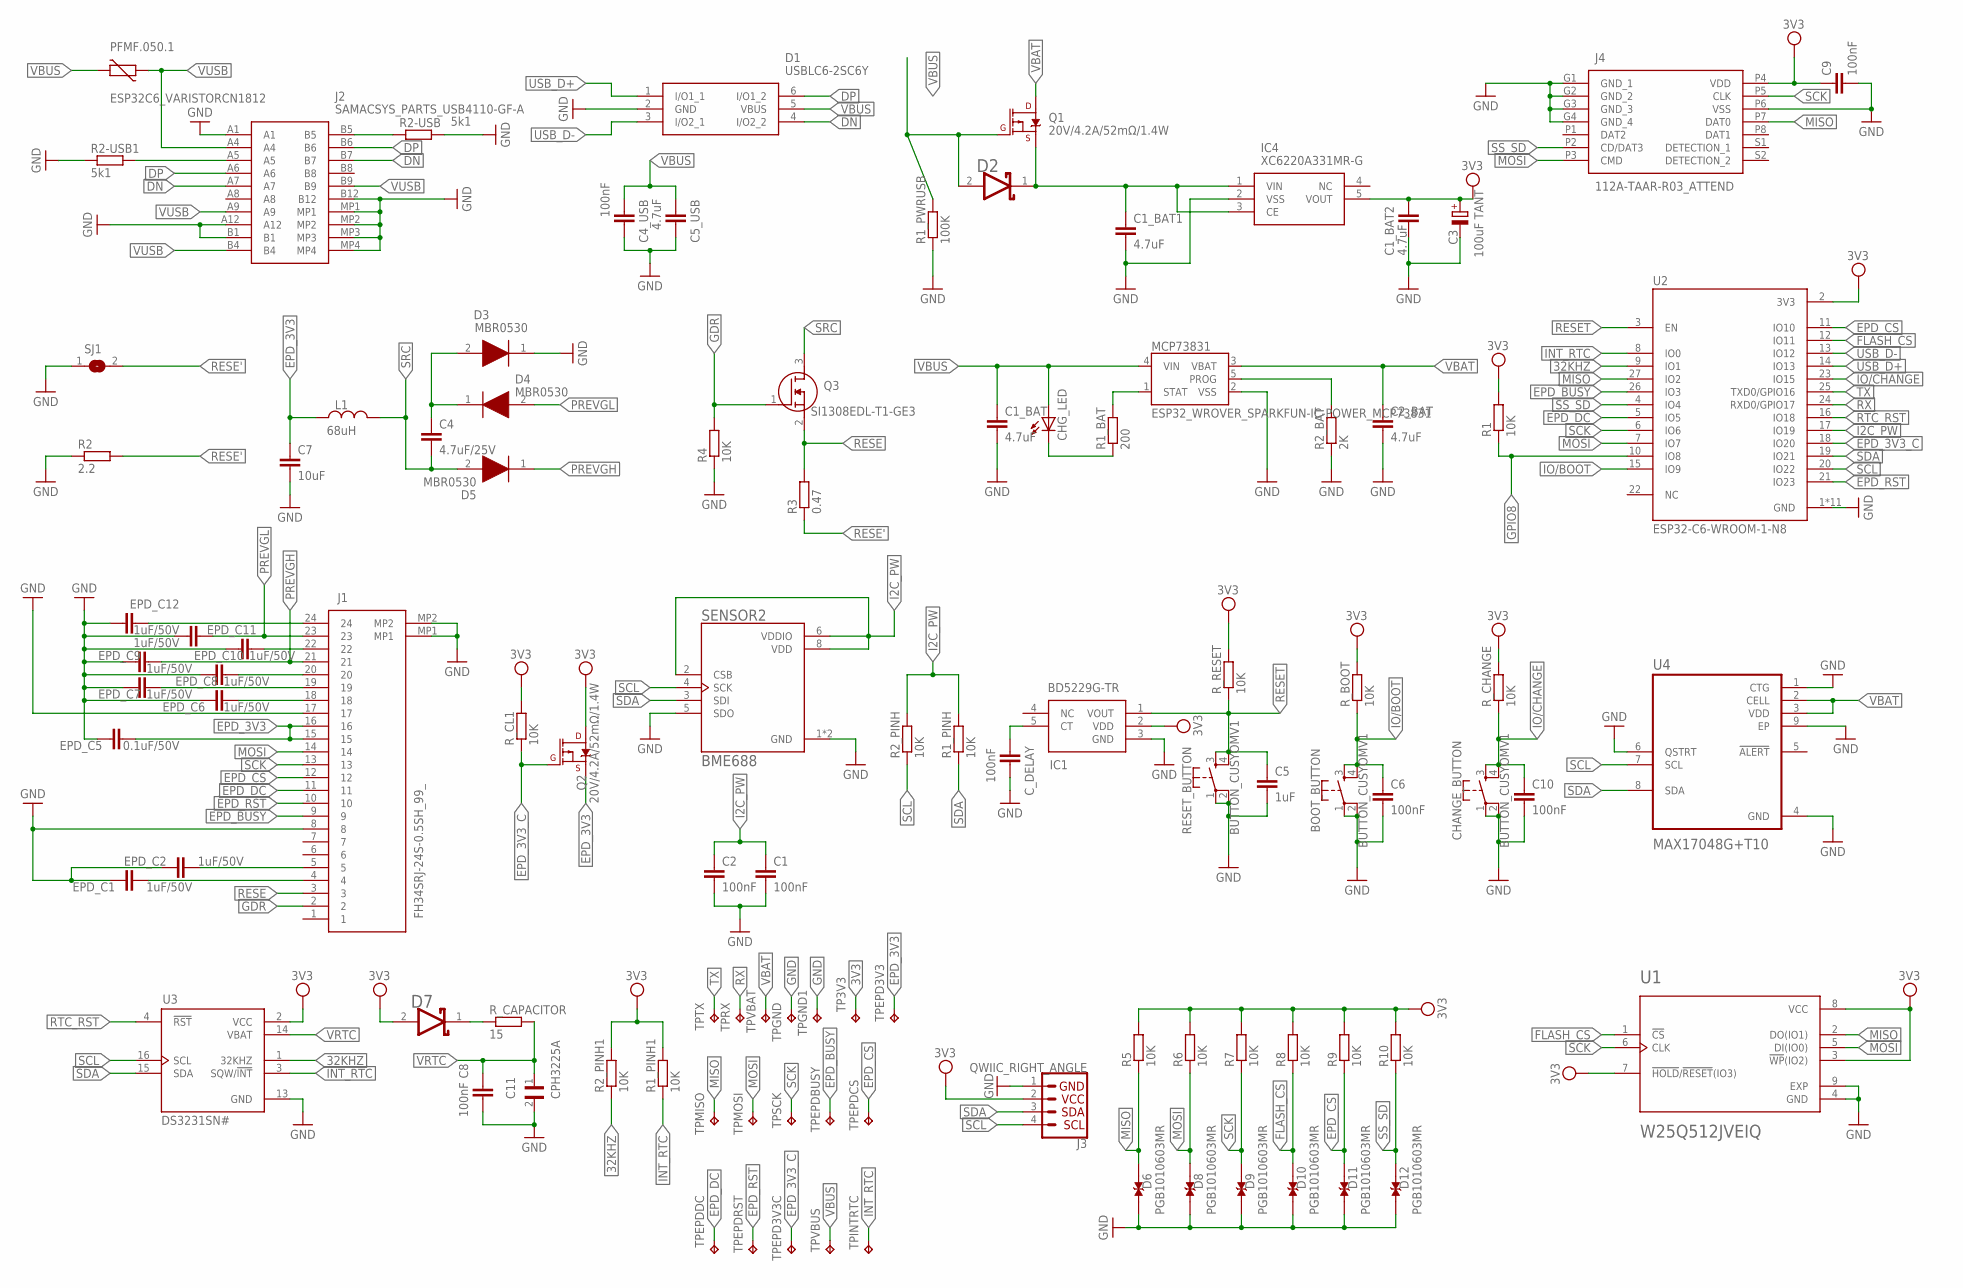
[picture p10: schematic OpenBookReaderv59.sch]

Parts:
BOOT_BUTTON: BUTTON_CUSYOMV1; MYBUTTON
C1, C2, C4_USB, C6, C8, C9, C10: 100nF; EAGLE-LTSPICE_C0402
C1_BAT, C1_BAT1, C1_BAT2, C2_BAT, C5_USB: 4.7uF; EAGLE-LTSPICE_C0402
C3: 100uF TANT; RCL_CT3528
C4: 4.7uF/25V; EAGLE-LTSPICE_C0402
C5: 1uF; EAGLE-LTSPICE_C0402
C7: 10uF; EAGLE-LTSPICE_C0402
C11: CPH3225A; CAPCP3225X100N
CHANGE_BUTTON: BUTTON_CUSYOMV1; MYBUTTON
CHG_LED: ADAFRUIT_LEDCHIP-LED0603; ADAFRUIT_CHIP-LED0603
C_DELAY: 100nF; EAGLE-LTSPICE_C0402
D1: USBLC6-2SC6Y; SOT95P280X145-6N
D2, D7: ESP32_WROVER_AVX---SD0805S020S1R0_AVX_SD0805S020S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; ESP32_WROVER_AVX---SD0805S020S1R0_AVX_SD0805S020S1R0_0
D3, D4, D5: MBR0530; SOD3716X135N
D6, D8, D9, D10, D11, D12: PGB1010603MR; DIOC1608X36N
EPD_C1, EPD_C2, EPD_C6, EPD_C7, EPD_C8, EPD_C9, EPD_C10, EPD_C11, EPD_C12: 1uF/50V; EAGLE-LTSPICE_C0402
EPD_C5: 0.1uF/50V; EAGLE-LTSPICE_C0402
IC1: BD5229G-TR; SOT95P280X125-5N
IC4: XC6220A331MR-G; SOT95P280X120-5N
J1: FH34SRJ-24S-0.5SH_99_; FH34SRJ24S05SH99
J2: SAMACSYS_PARTS_USB4110-GF-A; SAMACSYS_PARTS_USB4110GFA
J3: QWIIC_RIGHT_ANGLE; JST04_1MM_RA
J4: 112A-TAAR-R03_ATTEND; 112ATAARR03ATTEND
L1: 68uH; INDC1006X60N
MCP73831: ESP32_WROVER_SPARKFUN-IC-POWER_MCP73831; ESP32_WROVER_SPARKFUN-IC-POWER_SOT23-5
PFMF.050.1: ESP32C6_VARISTORCN1812; ESP32C6_VARISTOR_CT/CN1812
Q1, Q2: 20V/4.2A/52mΩ/1.4W; ESP32_WROVER_SPARKFUN-DISCRETESEMI_SOT23-3
Q3: SI1308EDL-T1-GE3; SOT65P210X110-3N
R1, R1_PINH, R1_PINH1, R2_PINH, R2_PINH1, R4, R5, R6, R7, R8, R9, R10: 10K; ESP32_WROVER_EAGLE-LTSPICE_R0402
R1_BAT: 200; ESP32_WROVER_EAGLE-LTSPICE_R0402
R1_PWRUSB: 100K; ESP32_WROVER_EAGLE-LTSPICE_R0402
R2: 2.2; ESP32_WROVER_EAGLE-LTSPICE_R0402
R2-USB, R2-USB1: 5k1; ESP32_WROVER_EAGLE-LTSPICE_R0402
R2_BAT: 2K; ESP32_WROVER_EAGLE-LTSPICE_R0402
R3: 0.47; ESP32_WROVER_EAGLE-LTSPICE_R0402
RESET_BUTTON: BUTTON_CUSYOMV1; MYBUTTON
R_BOOT: 10K; ESP32_WROVER_EAGLE-LTSPICE_R0402
R_CAPACITOR: 15; ESP32_WROVER_EAGLE-LTSPICE_R0402
R_CHANGE: 10K; ESP32_WROVER_EAGLE-LTSPICE_R0402
R_CL1: 10K; ESP32_WROVER_EAGLE-LTSPICE_R0402
R_RESET: 10K; ESP32_WROVER_EAGLE-LTSPICE_R0402
SENSOR2: BME688; ESP32_WROVER_BME680_PSON80P300X300X100-8N
SJ1: SJ
TP3V3: TPTP20R; TP20R
TPEPD3V3, TPEPD3V3C: TPTP20R; TP20R
TPEPDBUSY: TPTP20R; TP20R
TPEPDCS: TPTP20R; TP20R
TPEPDDC: TPTP20R; TP20R
TPEPDRST: TPTP20R; TP20R
TPGND, TPGND1: TPTP20R; TP20R
TPINTRTC: TPTP20R; TP20R
TPMISO: TPTP20R; TP20R
TPMOSI: TPTP20R; TP20R
TPRX: TPTP20R; TP20R
TPSCK: TPTP20R; TP20R
TPTX: TPTP20R; TP20R
TPVBAT: TPTP20R; TP20R
TPVBUS: TPTP20R; TP20R
U1: W25Q512JVEIQ; SON127P600X800X80-9N
U2: ESP32-C6-WROOM-1-N8; XCVR_ESP32-C6-WROOM-1-N8
U3: DS3231SN#; SOIC127P1032X265-16N
U4: MAX17048G+T10; SON50P200X200X80-9N

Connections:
3V3: C1_BAT2.1, C3.+, C9.1, D7.2 (ANODE), IC1.2 (VDD), IC4.5 (VOUT), J3.2, J4.P4 (VDD), Q2.3 (D), R1.2, R1_PINH1.2, R2_PINH1.2, R5.2, R6.2, R7.2, R8.2, R9.2, R10.2, R_BOOT.2, R_CHANGE.2, R_CL1.2, R_RESET.2, TP3V3.TP, U1.3 (!WP!(IO2)), U1.7 (!HOLD!/!RESET!(IO3)), U1.8 (VCC), U2.2 (3V3), U3.2 (VCC)
32KHZ: R2_PINH1.1, U2.9 (IO1), U3.1 (32KHZ)
DN: D1.4 (I/O2_2), J2.A7, J2.B7
DP: D1.6 (I/O1_2), J2.A6, J2.B6
EPD_3V3: C7.1, EPD_C5.2, J1.15, J1.16, L1.1, Q2.2 (S), TPEPD3V3.TP
EPD_3V3_C: Q2.1 (G), R_CL1.1, TPEPD3V3C.TP, U2.18 (IO20)
EPD_BUSY: J1.9, TPEPDBUSY.TP, U2.26 (IO3)
EPD_CS: D11.2, J1.12, R9.1, TPEPDCS.TP, U2.11 (IO10)
EPD_DC: J1.11, TPEPDDC.TP, U2.5 (IO5)
EPD_RST: J1.10, TPEPDRST.TP, U2.21 (IO23)
FLASH_CS: D10.2, R8.1, U1.1 (!CS), U2.12 (IO11)
GDR: J1.2, Q3.1 (G), R4.2
GND: BOOT_BUTTON.1, BOOT_BUTTON.2, C1.2, C1_BAT.2, C1_BAT1.2, C1_BAT2.2, C2.2, C2_BAT.2, C3.-, C4_USB.2, C5.2, C5_USB.2, C6.2, C7.2, C8.2, C9.2, C10.2, C11.2, CHANGE_BUTTON.1, CHANGE_BUTTON.2, C_DELAY.2, D1.2 (GND), D3.1 (K), D6.1, D8.1, D9.1, D10.1, D11.1, D12.1, EPD_C1.1, EPD_C2.1, EPD_C5.1, EPD_C6.1, EPD_C7.1, EPD_C8.1, EPD_C9.1, EPD_C10.1, EPD_C11.1, EPD_C12.1, IC1.3 (GND), IC4.2 (VSS), J1.8, J1.17, J1.MP1, J1.MP2, J2.A1, J2.A12, J2.B1, J2.B12, J2.MP1, J2.MP2, J2.MP3, J2.MP4, J3.1, J4.G1 (GND_1), J4.G2 (GND_2), J4.G3 (GND_3), J4.G4 (GND_4), J4.P6 (VSS), MCP73831.2 (VSS), R1_PWRUSB.1, R2.1, R2-USB.2, R2-USB1.1, R2_BAT.1, R4.1, RESET_BUTTON.1, RESET_BUTTON.2, SENSOR2.1 (GND), SENSOR2.5 (SDO), SENSOR2.7 (GND), SJ1.1, TPGND.TP, TPGND1.TP, U1.4 (GND), U1.9 (EXP), U2.1 (GND), U2.28 (GND), U2.29_1 (GND), U2.29_2 (GND), U2.29_3 (GND), U2.29_4 (GND), U2.29_5 (GND), U2.29_6 (GND), U2.29_7 (GND), U2.29_8 (GND), U2.29_9 (GND), U3.13 (GND), U4.1 (CTG), U4.4 (GND), U4.6 (QSTRT), U4.9 (EP)
GPIO8: R1.1, U2.10 (IO8)
I2C_PW: C1.1, C2.1, R1_PINH.2, R2_PINH.2, SENSOR2.2 (CSB), SENSOR2.6 (VDDIO), SENSOR2.8 (VDD), U2.17 (IO19)
INT_RTC: R1_PINH1.1, TPINTRTC.TP, U2.8 (IO0), U3.3 (SQW/!INT)
IO/BOOT: BOOT_BUTTON.3, BOOT_BUTTON.4, C6.1, R_BOOT.1, U2.15 (IO9)
IO/CHANGE: C10.1, CHANGE_BUTTON.3, CHANGE_BUTTON.4, R_CHANGE.1, U2.23 (IO15)
MISO: D6.2, J4.P7 (DAT0), R5.1, TPMISO.TP, U1.2 (DO(IO1)), U2.27 (IO2)
MOSI: D8.2, J1.14, J4.P3 (CMD), R6.1, TPMOSI.TP, U1.5 (DI(IO0)), U2.7 (IO7)
unnamed: J2.A5, R2-USB1.2
unnamed: J2.B5, R2-USB.1
unnamed: C1_BAT1.1, D2.1 (CATHODE), IC4.1 (VIN), IC4.3 (CE), Q1.2 (S)
unnamed: MCP73831.1 (STAT), R1_BAT.2
unnamed: C4.1, D3.2 (A), D4.1 (K)
unnamed: CHG_LED.C, R1_BAT.1
unnamed: MCP73831.5 (PROG), R2_BAT.2
unnamed: EPD_C12.2, J1.24
unnamed: EPD_C10.2, J1.22
unnamed: EPD_C8.2, J1.20
unnamed: EPD_C7.2, J1.19
unnamed: EPD_C6.2, J1.18
unnamed: EPD_C2.2, J1.5
unnamed: EPD_C1.2, J1.4
unnamed: C_DELAY.1, IC1.5 (CT)
unnamed: D7.1 (CATHODE), R_CAPACITOR.1
PREVGH: D5.1 (K), EPD_C9.2, J1.21
PREVGL: D4.2 (A), EPD_C11.2, J1.23
RESE: J1.3, Q3.2 (S), R3.2
RESE': R2.2, R3.1, SJ1.2
RESET: C5.1, IC1.1 (VOUT), RESET_BUTTON.3, RESET_BUTTON.4, R_RESET.1, U2.3 (EN)
RTC_RST: U2.16 (IO18), U3.4 (!RST)
RX: TPRX.TP, U2.24 (RXD0/GPIO17)
SCK: D9.2, J1.13, J4.P5 (CLK), R7.1, TPSCK.TP, U1.6 (CLK), U2.6 (IO6)
SCL: J3.4, R2_PINH.1, SENSOR2.4 (SCK), U2.20 (IO22), U3.16 (SCL), U4.7 (SCL)
SDA: J3.3, R1_PINH.1, SENSOR2.3 (SDI), U2.19 (IO21), U3.15 (SDA), U4.8 (SDA)
SRC: C4.2, D5.2 (A), L1.2, Q3.3 (D)
SS_SD: D12.2, J4.P2 (CD/DAT3), R10.1, U2.4 (IO4)
TX: TPTX.TP, U2.25 (TXD0/GPIO16)
USB_D+: D1.1 (I/O1_1), U2.14 (IO13)
USB_D-: D1.3 (I/O2_1), U2.13 (IO12)
VBAT: C2_BAT.1, MCP73831.3 (VBAT), Q1.3 (D), TPVBAT.TP, U4.2 (CELL), U4.3 (VDD)
VBUS: C1_BAT.1, C4_USB.1, C5_USB.1, CHG_LED.A, D1.5 (VBUS), D2.2 (ANODE), MCP73831.4 (VIN), PFMF.050.1.2, Q1.1 (G), R1_PWRUSB.2, TPVBUS.TP
VRTC: C8.1, C11.1, R_CAPACITOR.2, U3.14 (VBAT)
VUSB: J2.A4, J2.A9, J2.B4, J2.B9, PFMF.050.1.1

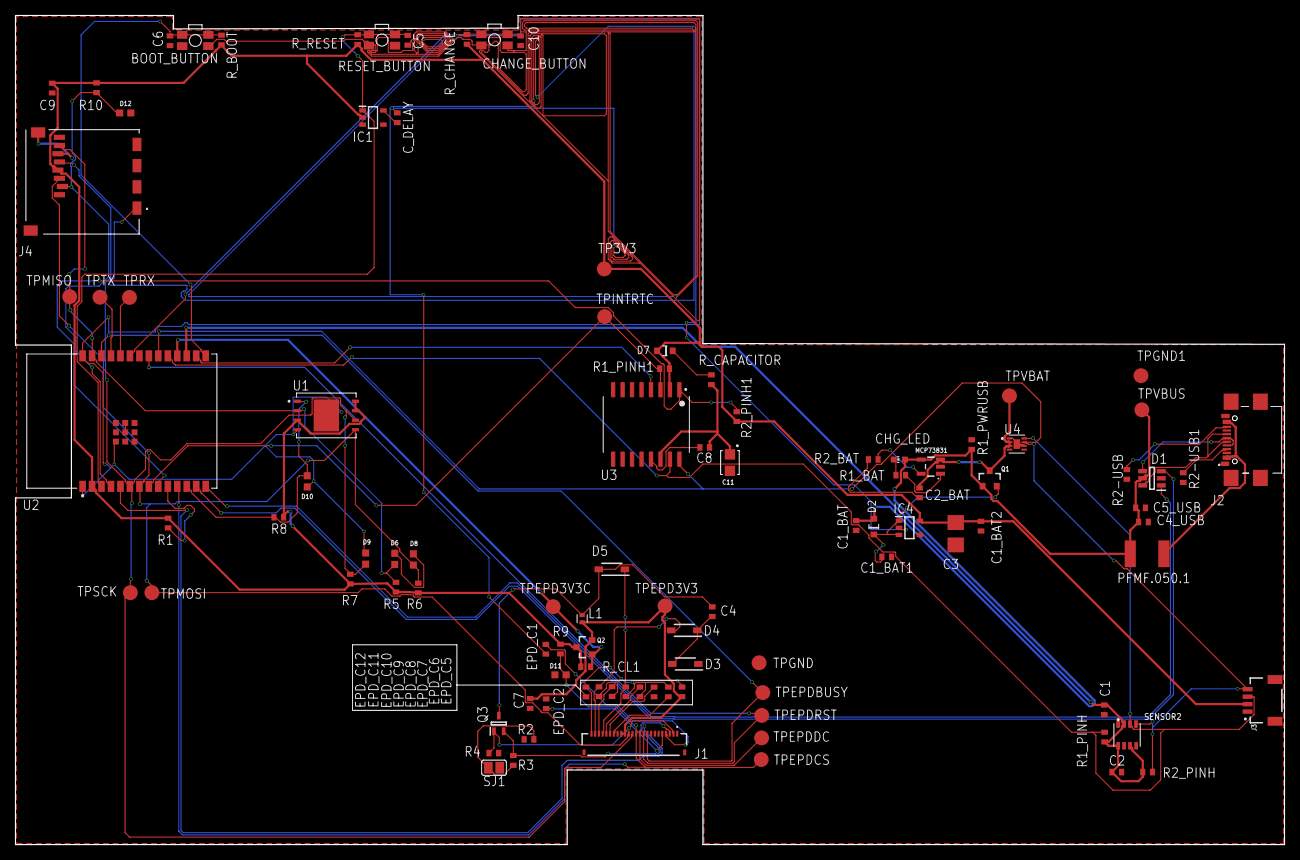
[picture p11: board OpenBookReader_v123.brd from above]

Board: 2 copper layers, 170.2 x 111.2 mm, 103 parts (0 on the bottom side), 55 nets.

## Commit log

2025-03-31 Pick and place+BOM+Gerbers
    [OpenBookReader v109.csv, PnP_OpenBookReader v109_front.csv]
2025-03-31 Mechanical.zip upload
    Contains an expldoed view model and the fully assembled model
2025-04-02 Renew sd card
    [OpenBookReaderv113.brd]
